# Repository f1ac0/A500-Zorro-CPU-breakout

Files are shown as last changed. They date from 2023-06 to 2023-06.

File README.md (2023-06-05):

# A500-Zorro-CPU-breakout
This is a breakout PCB with a DIP64 68000 CPU socket that plugs into the Amiga 500 expansion port. It has no active part and is designed to just move the original 68000 outside the system, host a 68000 CPU replacement, or an expansion designed to seat under the CPU. It should be helpful for design and test purposes, and may use a ZIF-64 socket.

It is designed as a 2 layers board and to fit in the dimensions for cheap PCB manufacturing ; because of this it requires an additional small board for the power pins of the expansion connector (or two additional wires).

Beware that the 68000 is rotated 180° from how it is on the A500 motherboard : its pin 1 is on the top left instead of bottom right. This made the PCB routing a bit more complicated but should allow to install the boards that normally expand over the ROM or Denise chips.

If your CPU replacement does not use bus arbitration to take over the 68k bus, then the CPU on the A500 motherboard must be removed.

Depending on your A500 motherboard revision, you may have to close its JP6 jumper to feed the 7MHz clock to the expansion connector.

# Disclaimer
This is a hobbyist project, it comes with no warranty and no support. Also remember that the Amiga machines are about 30 years old and may fail because of such hardware expansions.

I publish my work under the CC-BY-NC-SA license.

If you find it useful and want to reward my hard work : I am always looking for Amiga/Amstrad CPC/Commodore hardware to repair and hack, please contact me.

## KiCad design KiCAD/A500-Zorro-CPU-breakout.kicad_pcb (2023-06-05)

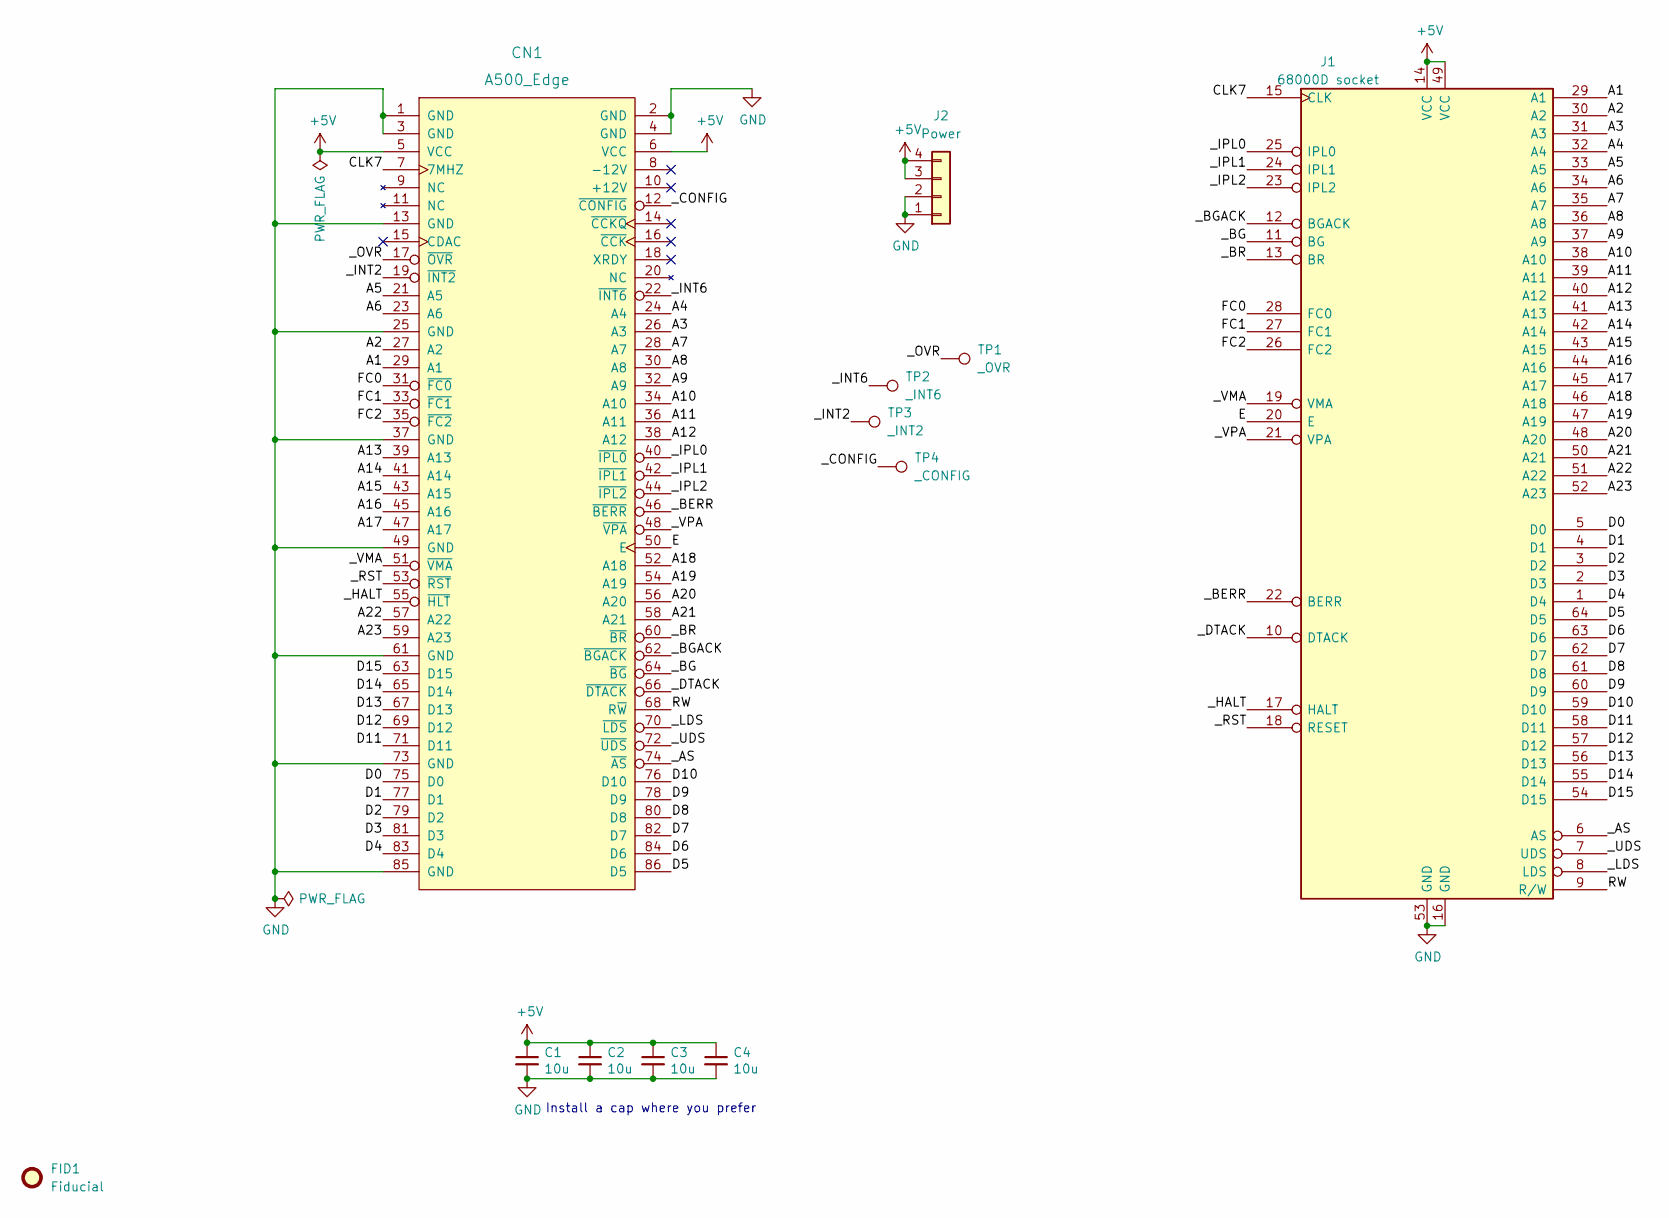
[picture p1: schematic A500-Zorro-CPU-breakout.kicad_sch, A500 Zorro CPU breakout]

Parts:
C1, C2, C3, C4: 10u; C_0805_2012Metric
CN1: A500_Edge; A500_ExpansionSocket_2x43_P2.54mm_5mm
FID1: Fiducial; CC_BY_NC_SA_long_silkscreen
J1: 68000D socket; DIP-64_W22.86mm_Socket_LongPads_BigHoles1.0
J2: Power; PinHeader_1x04_P2.54mm_Vertical
TP1: _OVR; TestPoint_THTPad_D1.7mm_Drill1.0mm
TP2: _INT6; TestPoint_THTPad_D1.7mm_Drill1.0mm
TP3: _INT2; TestPoint_THTPad_D1.7mm_Drill1.0mm
TP4: _CONFIG; TestPoint_THTPad_D1.7mm_Drill1.0mm

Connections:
+5V: C1.1, C2.1, C3.1, C4.1, CN1.5 (VCC), CN1.6 (VCC), J1.14 (VCC), J1.49 (VCC), J2.3, J2.4
/A1: CN1.29 (A1), J1.29 (A1)
/A2: CN1.27 (A2), J1.30 (A2)
/A3: CN1.26 (A3), J1.31 (A3)
/A4: CN1.24 (A4), J1.32 (A4)
/A5: CN1.21 (A5), J1.33 (A5)
/A6: CN1.23 (A6), J1.34 (A6)
/A7: CN1.28 (A7), J1.35 (A7)
/A8: CN1.30 (A8), J1.36 (A8)
/A9: CN1.32 (A9), J1.37 (A9)
/A10: CN1.34 (A10), J1.38 (A10)
/A11: CN1.36 (A11), J1.39 (A11)
/A12: CN1.38 (A12), J1.40 (A12)
/A13: CN1.39 (A13), J1.41 (A13)
/A14: CN1.41 (A14), J1.42 (A14)
/A15: CN1.43 (A15), J1.43 (A15)
/A16: CN1.45 (A16), J1.44 (A16)
/A17: CN1.47 (A17), J1.45 (A17)
/A18: CN1.52 (A18), J1.46 (A18)
/A19: CN1.54 (A19), J1.47 (A19)
/A20: CN1.56 (A20), J1.48 (A20)
/A21: CN1.58 (A21), J1.50 (A21)
/A22: CN1.57 (A22), J1.51 (A22)
/A23: CN1.59 (A23), J1.52 (A23)
/CLK7: CN1.7 (7MHZ), J1.15 (CLK)
/D0: CN1.75 (D0), J1.5 (D0)
/D1: CN1.77 (D1), J1.4 (D1)
/D2: CN1.79 (D2), J1.3 (D2)
/D3: CN1.81 (D3), J1.2 (D3)
/D4: CN1.83 (D4), J1.1 (D4)
/D5: CN1.86 (D5), J1.64 (D5)
/D6: CN1.84 (D6), J1.63 (D6)
/D7: CN1.82 (D7), J1.62 (D7)
/D8: CN1.80 (D8), J1.61 (D8)
/D9: CN1.78 (D9), J1.60 (D9)
/D10: CN1.76 (D10), J1.59 (D10)
/D11: CN1.71 (D11), J1.58 (D11)
/D12: CN1.69 (D12), J1.57 (D12)
/D13: CN1.67 (D13), J1.56 (D13)
/D14: CN1.65 (D14), J1.55 (D14)
/D15: CN1.63 (D15), J1.54 (D15)
/E: CN1.50 (E), J1.20 (E)
/FC0: CN1.31 (~FC0), J1.28 (FC0)
/FC1: CN1.33 (~FC1), J1.27 (FC1)
/FC2: CN1.35 (~FC2), J1.26 (FC2)
/RW: CN1.68 (R~W), J1.9 (R/W)
/_AS: CN1.74 (~AS), J1.6 (AS)
/_BERR: CN1.46 (~BERR), J1.22 (BERR)
/_BG: CN1.64 (~BG), J1.11 (BG)
/_BGACK: CN1.62 (~BGACK), J1.12 (BGACK)
/_BR: CN1.60 (~BR), J1.13 (BR)
/_CONFIG: CN1.12 (~CONFIG), TP4.1
/_DTACK: CN1.66 (~DTACK), J1.10 (DTACK)
/_HALT: CN1.55 (~HLT), J1.17 (HALT)
/_INT2: CN1.19 (~INT2), TP3.1
/_INT6: CN1.22 (~INT6), TP2.1
/_IPL0: CN1.40 (~IPL0), J1.25 (IPL0)
/_IPL1: CN1.42 (~IPL1), J1.24 (IPL1)
/_IPL2: CN1.44 (~IPL2), J1.23 (IPL2)
/_LDS: CN1.70 (~LDS), J1.8 (LDS)
/_OVR: CN1.17 (~OVR), TP1.1
/_RST: CN1.53 (~RST), J1.18 (RESET)
/_UDS: CN1.72 (~UDS), J1.7 (UDS)
/_VMA: CN1.51 (~VMA), J1.19 (VMA)
/_VPA: CN1.48 (~VPA), J1.21 (VPA)
GND: C1.2, C2.2, C3.2, C4.2, CN1.1 (GND), CN1.2 (GND), CN1.3 (GND), CN1.4 (GND), CN1.13 (GND), CN1.25 (GND), CN1.37 (GND), CN1.49 (GND), CN1.61 (GND), CN1.73 (GND), CN1.85 (GND), J1.16 (GND), J1.53 (GND), J2.1, J2.2

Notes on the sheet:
Install a cap where you prefer

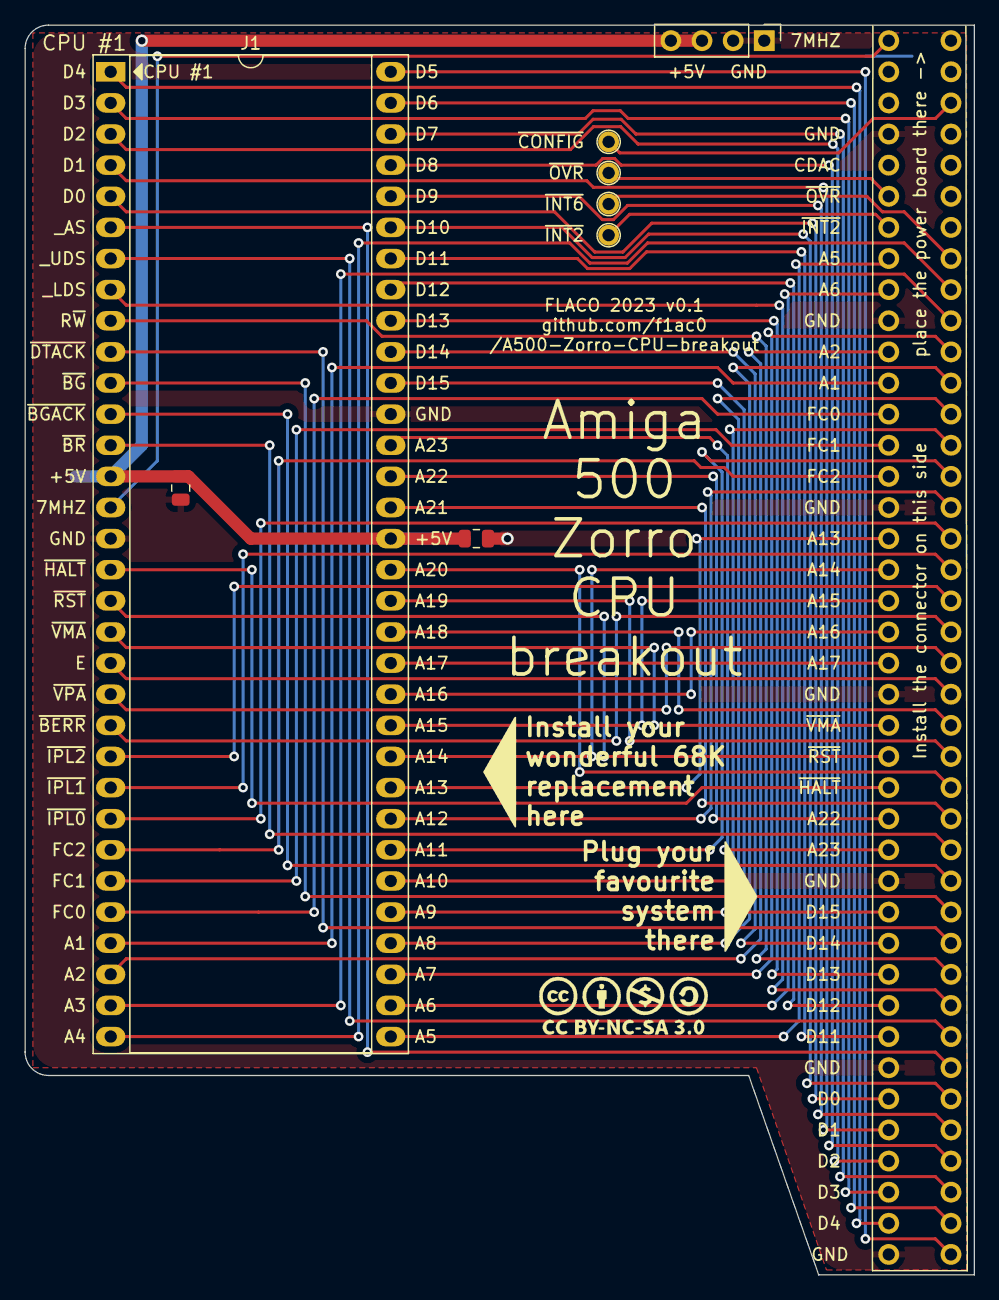
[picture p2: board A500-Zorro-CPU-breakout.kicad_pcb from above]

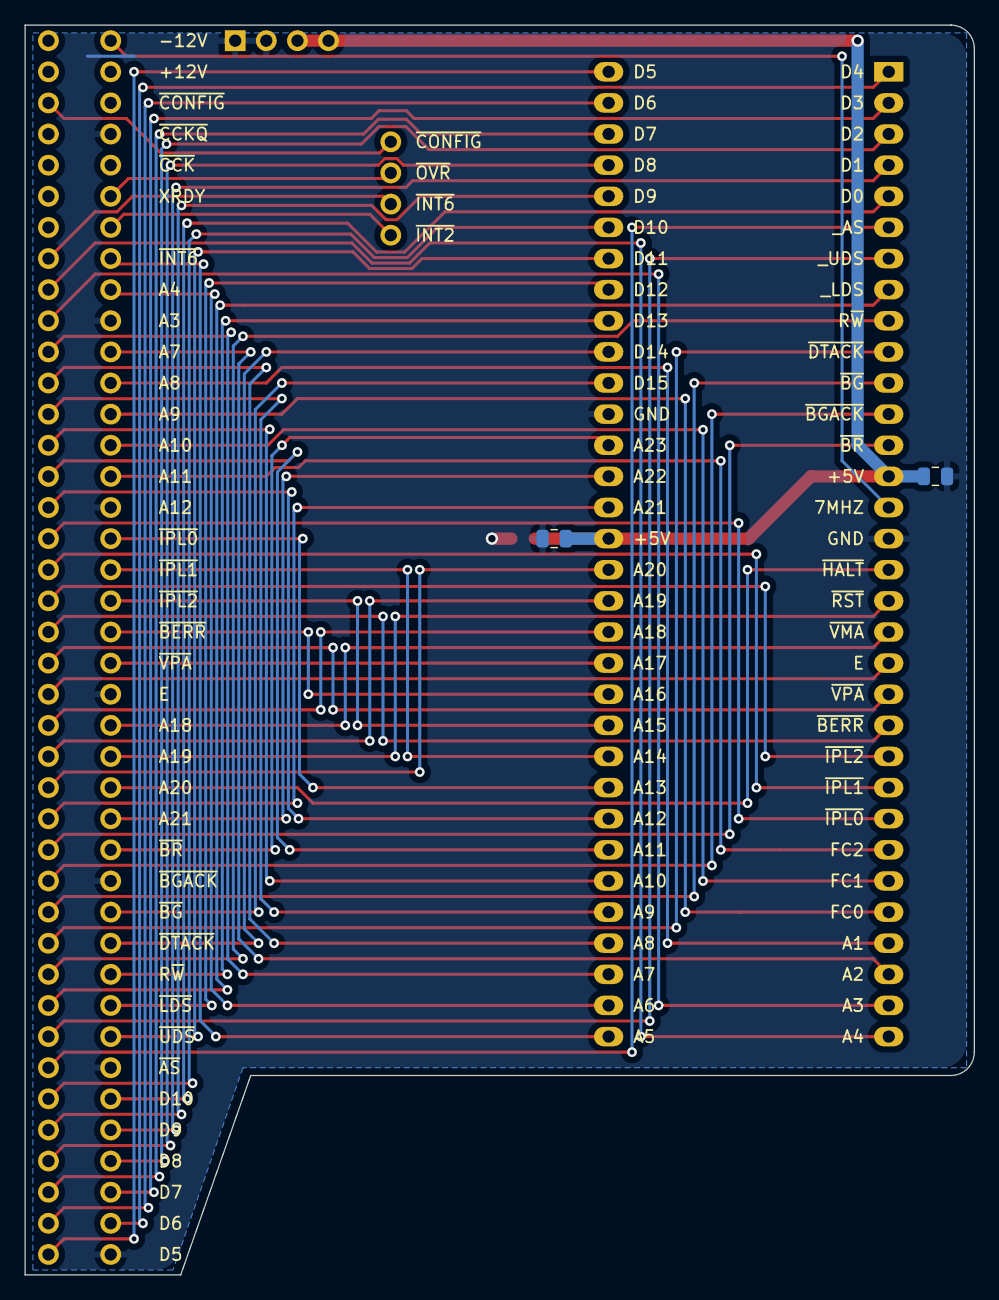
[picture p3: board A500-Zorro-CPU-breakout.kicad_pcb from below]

Board: 2 copper layers, 77.5 x 102.0 mm, 12 parts (2 on the bottom side), 66 nets.

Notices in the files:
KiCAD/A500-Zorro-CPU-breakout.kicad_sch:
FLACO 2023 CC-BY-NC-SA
